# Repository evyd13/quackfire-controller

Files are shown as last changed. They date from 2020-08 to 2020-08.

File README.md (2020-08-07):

# Quackfire controller rev1

This is a replacement controller for the CM Quickfire Rapid. Everything works, except for the WinLock LED (which isn't connected to the controller).

## Building
If you feel like building a few of these PCBs yourself, go to the 'Releases' tab and download the latest gerber files. Order those at your favourite PCB manufacturer, get the components needed (see below) and solder them on! A hot air station is not required but a good soldering iron is. Flux is recommended.

## Opening the project
To open the files you will need the latest KiCAD nightly version.

## Bill of materials (BOM)
Amount is per PCB, multiply as needed.

| LCSC part # | Description | Value | Package  | Amount |
| --- | --- | ----- | --- | ---:|
| C83060 | Capacitor | 0.1uF | 0603 | 4 |
| C131056 | Capacitor | 4.7uF | 0805 | 1 |
| C302042 | Capacitor | 1uF | 0603 | 1 |
| C261942 | Fuse | | 0805 | 1 |
| C98220 | Resistor | 10K | 0603 | 2 |
| C12028 | Resistor | 5.1K  | 0603 | 2 |
| C384264 | Resistor | 22 | 0603 | 2 |
| C44854 | MCU | 32U4  | QFP-44 | 1 |
| C341521 | Resonator | 16MHz | SMD | 1 |
| | 2x10 2.00mm pin header  | | THT | 2 |

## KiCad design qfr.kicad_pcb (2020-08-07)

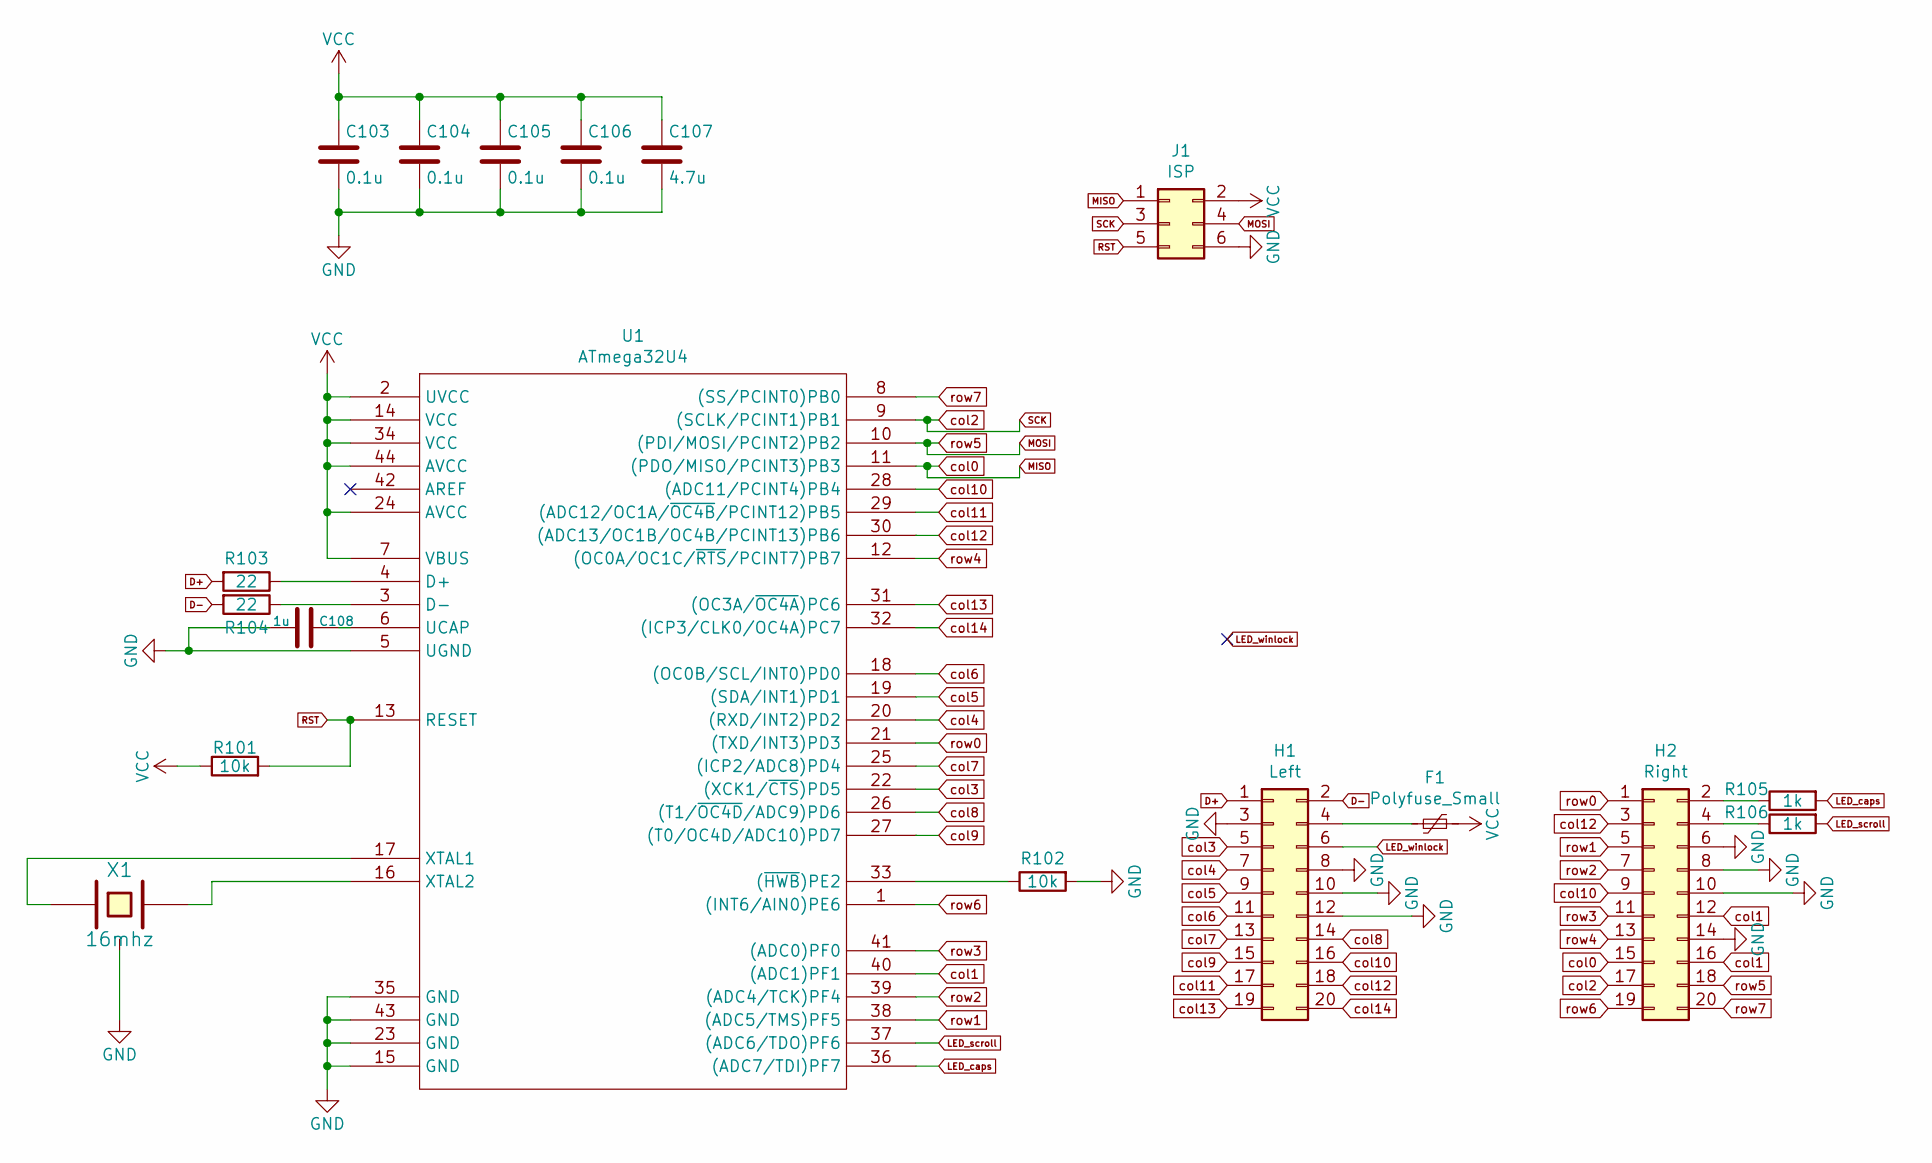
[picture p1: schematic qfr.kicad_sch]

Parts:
C103, C104, C105, C106: 0.1u; C_0603
C107: 4.7u; C_0805
C108: 1u; C_0603
F1: Polyfuse_Small; R_0805
H1: Left; PinHeader_2x10_P2.00mm_Vertical
H2: Right; PinHeader_2x10_P2.00mm_Vertical
J1: ISP; isp_standard
R101, R102: 10k; R_0603
R103, R104: 22; R_0603
R105, R106: 1k; R_0603
U1: ATmega32U4; ATMEGA32U4
X1: 16mhz; Resonator_SMD_muRata_CSTNExxV-3Pin-p1.2

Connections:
D+: H1.1, R103.2
D-: H1.2, R104.2
GND: C103.2, C104.2, C105.2, C106.2, C107.2, C108.2, H1.3, H1.8, H1.10, H1.12, H2.6, H2.8, H2.10, H2.14, J1.6, R102.2, U1.5 (UGND), U1.15 (GND), U1.23 (GND), U1.35 (GND), U1.43 (GND), X1.3
LED_caps: R105.2, U1.36 ((ADC7/TDI)PF7)
LED_scroll: R106.2, U1.37 ((ADC6/TDO)PF6)
MISO: H2.15, J1.1, U1.11 ((PDO/MISO/PCINT3)PB3)
MOSI: H2.18, J1.4, U1.10 ((PDI/MOSI/PCINT2)PB2)
unnamed: C108.1, U1.6 (UCAP)
unnamed: F1.1, H1.4
unnamed: H2.2, R105.1
unnamed: H2.4, R106.1
unnamed: R102.1, U1.33 ((~HWB~)PE2)
unnamed: R103.1, U1.4 (D+)
unnamed: R104.1, U1.3 (D-)
unnamed: U1.16 (XTAL2), X1.2
unnamed: U1.17 (XTAL1), X1.1
RST: J1.5, R101.2, U1.13 (RESET)
SCK: H2.17, J1.3, U1.9 ((SCLK/PCINT1)PB1)
VCC: C103.1, C104.1, C105.1, C106.1, C107.1, F1.2, J1.2, R101.1, U1.2 (UVCC), U1.7 (VBUS), U1.14 (VCC), U1.24 (AVCC), U1.34 (VCC), U1.44 (AVCC)
col1: H2.12, H2.16, U1.40 ((ADC1)PF1)
col3: H1.5, U1.22 ((XCK1/~CTS~)PD5)
col4: H1.7, U1.20 ((RXD/INT2)PD2)
col5: H1.9, U1.19 ((SDA/INT1)PD1)
col6: H1.11, U1.18 ((OC0B/SCL/INT0)PD0)
col7: H1.13, U1.25 ((ICP2/ADC8)PD4)
col8: H1.14, U1.26 ((T1/~OC4D~/ADC9)PD6)
col9: H1.15, U1.27 ((T0/OC4D/ADC10)PD7)
col10: H1.16, H2.9, U1.28 ((ADC11/PCINT4)PB4)
col11: H1.17, U1.29 ((ADC12/OC1A/~OC4B~/PCINT12)PB5)
col12: H1.18, H2.3, U1.30 ((ADC13/OC1B/OC4B/PCINT13)PB6)
col13: H1.19, U1.31 ((OC3A/~OC4A~)PC6)
col14: H1.20, U1.32 ((ICP3/CLK0/OC4A)PC7)
row0: H2.1, U1.21 ((TXD/INT3)PD3)
row1: H2.5, U1.38 ((ADC5/TMS)PF5)
row2: H2.7, U1.39 ((ADC4/TCK)PF4)
row3: H2.11, U1.41 ((ADC0)PF0)
row4: H2.13, U1.12 ((OC0A/OC1C/~RTS~/PCINT7)PB7)
row6: H2.19, U1.1 ((INT6/AIN0)PE6)
row7: H2.20, U1.8 ((SS/PCINT0)PB0)

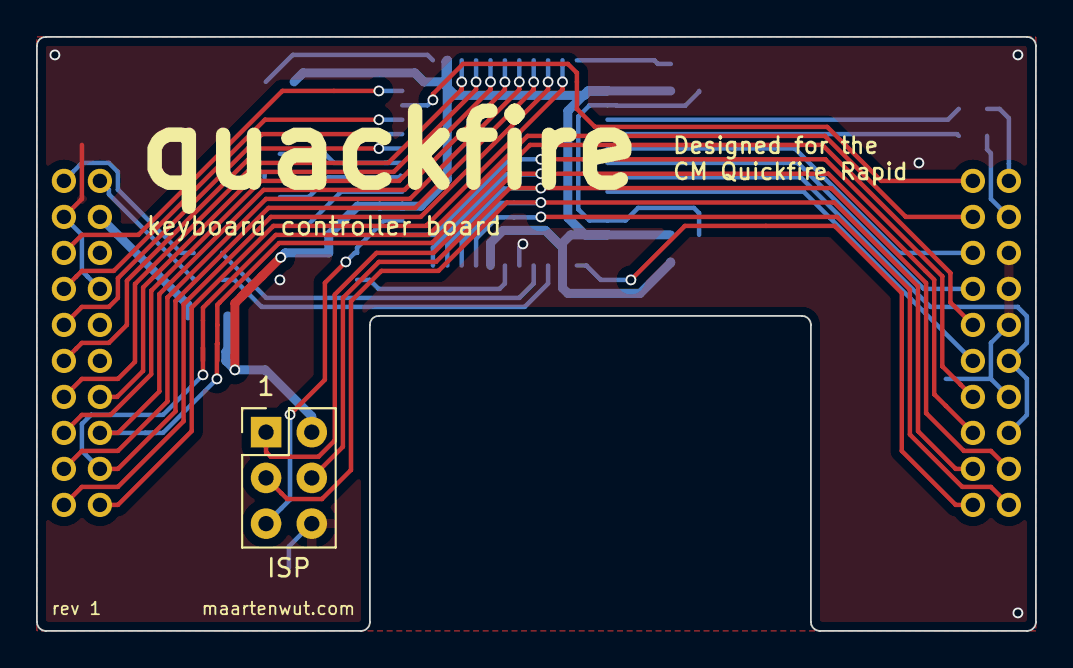
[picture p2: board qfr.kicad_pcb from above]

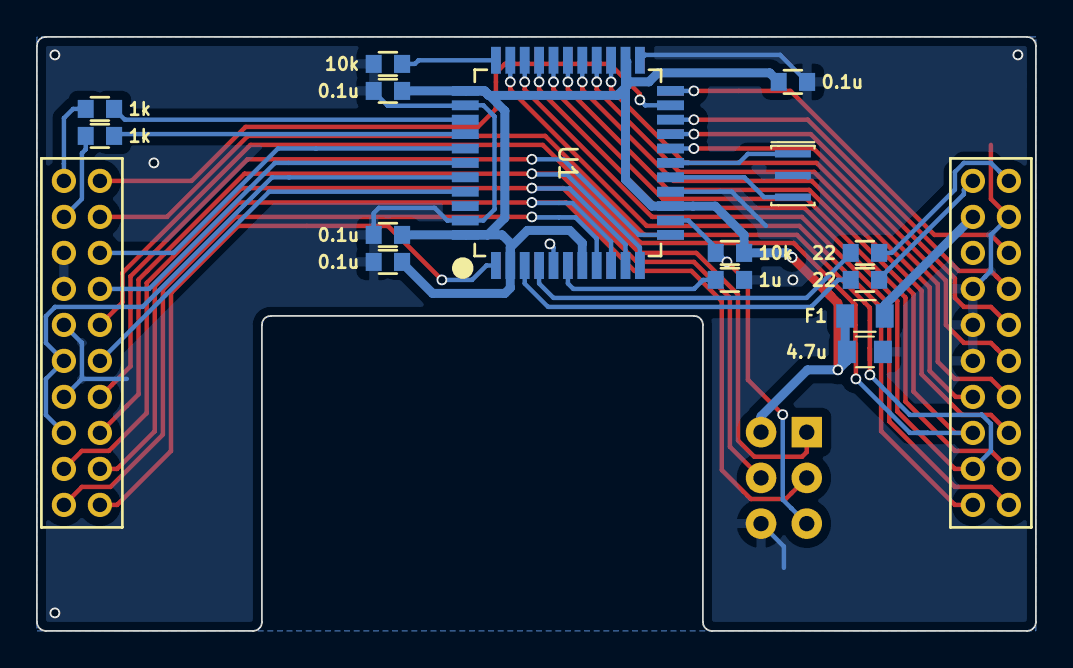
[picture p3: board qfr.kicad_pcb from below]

Board: 2 copper layers, 55.5 x 33.0 mm, 18 parts (15 on the bottom side), 39 nets.

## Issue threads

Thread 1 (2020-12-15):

unable to open qfr.kicad_pcb in kicad

anthonysymak, 2020-12-15:
kicad report error and cannot open file

evyd13, 2020-12-15:
such info

anthonysymak, 2020-12-15:
sorry about the lacking of information. kicad reports : error loading board file with path to qfr.kicad_pcb

evyd13, 2020-12-15:
*carefully* read the readme.md file

Closed 2020-12-15.
